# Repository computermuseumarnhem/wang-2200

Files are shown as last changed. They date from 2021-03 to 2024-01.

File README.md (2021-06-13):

# Wang 2200

I'd like to get this thing working again.

Therefore:

## Extension cards

I've created extension cards to be able to raise the the processor and interface cards out of the card cage. The boards are 8" (203.20 mm) long 
and 2.50" (63.5 mm) wide. In total three extension cards are needed for a full processor board, and two for an interface card, or the power regulator
card.

Features are:

- The card is raised outside the card cage and rotated 90 degrees (component side up). That makes it easy to probe signals with a multimeter or oscilloscope.
- A standard 2x15 0.1" header is provided that connects to all connection points on the card edge, for easy attachment of logic analyzer probes

## Power supply

The power supply consists of three parts

1. The transformer, the bulk filter capacitors, and a few resistors and diodes on the main board
2. The regulator board with the low power parts of the (linear) regulators (board L567)
3. The heat sink with the high power parts of the regulators (transistors and rectifiers)

The transformer and bulk filter capacitors are either soldered or screwed to the main board. The resistors and diodes are also soldered on the mainboard.

The regulator board is using the regular card edges (two 2 &times; 15 pads), also used on the other boards. These card edges mate with EDAC 307-030-520-201 card edge connectors.

The heat sink uses two TE Commercial MATE-N-LOK connectors, one 12 position (1-480287-0) and one 16 position (1-480438-0). The regulator board connects to the heat sink via the main board.

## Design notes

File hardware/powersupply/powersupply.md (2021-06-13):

# Powersupply

The powersupply consists of two parts:

1. The large and heavy stuff, mounted to the chassis
2. Some resistors, capacitors and diodes on the main board
3. The regulator board with the regulator electonics
4. The heat sink with the power transistors and diodes

The "Schematic Logibloc Interconnection Diagram" (D-6627-999) shows how the different parts connect together. However I don't expect the reality reflects the schematic completely.

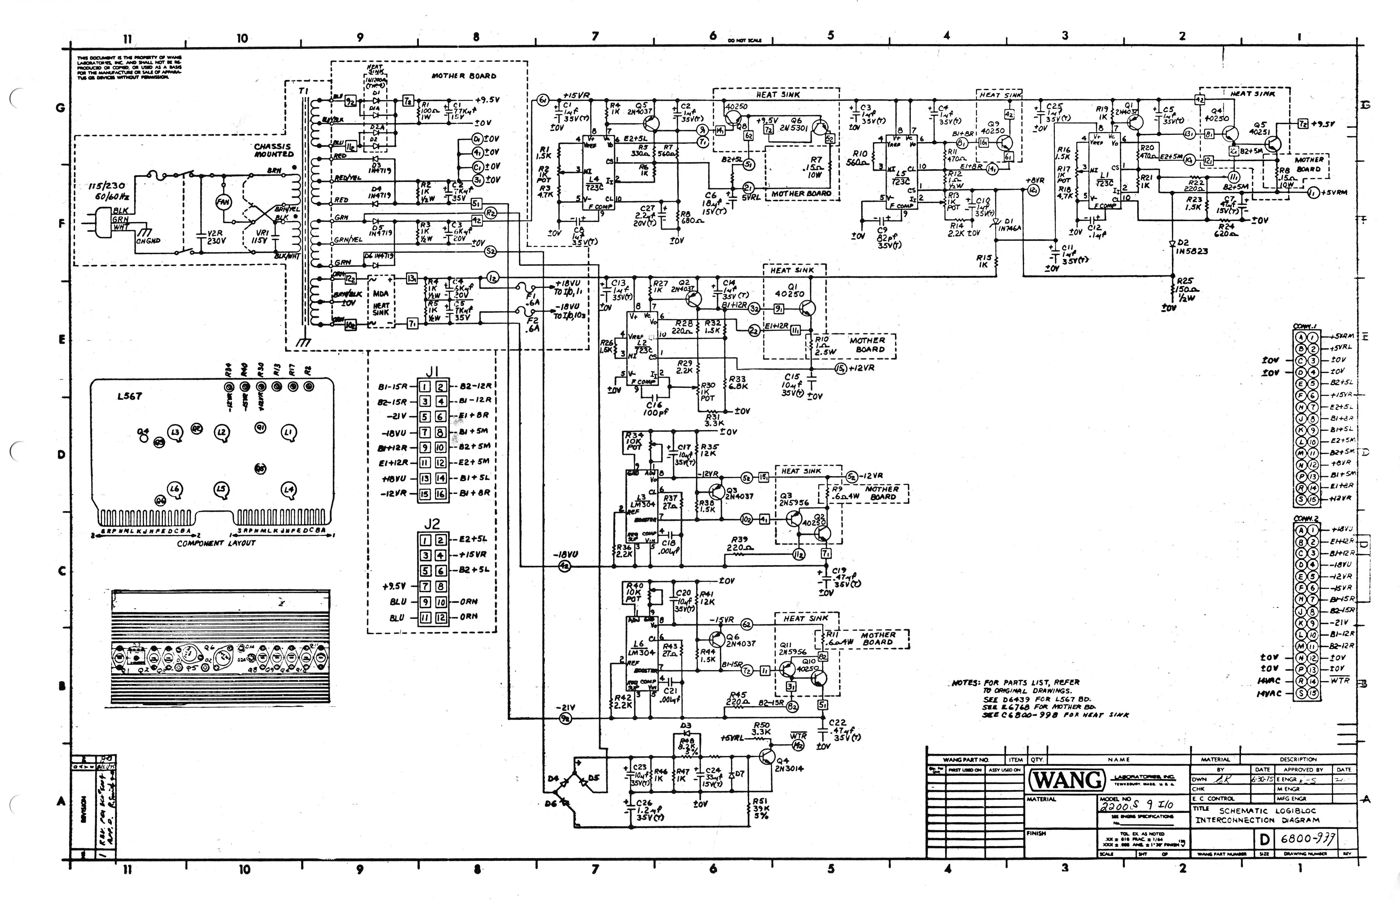
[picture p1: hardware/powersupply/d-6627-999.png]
D-6627-999


## 1. Large and heavy

The transformer is probably the largest and heaviest in the system. So this one's here. So is the cooling fan. Also the mains filter capacitors and two of the bulk filter capacitors. The last two are mounted on the chassis, and with their terminals directly screwed to the main board.

Contrary to the schematic, the mains filter capacitors are mounted to a small-ish circuit board, together with what looks like a large resistor, but could be anything (a cylinder 7.25mm diameter, 23 mm long, colour bands: silver, red, red, black, silver)

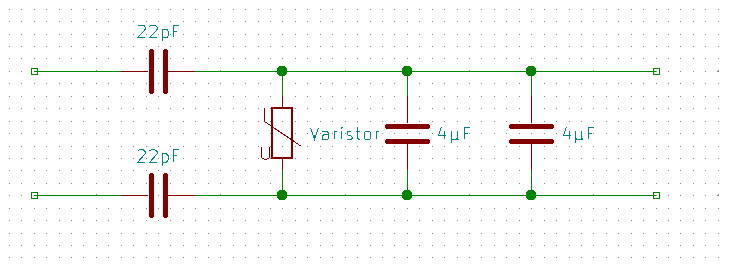
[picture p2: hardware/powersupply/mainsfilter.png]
Mains filter


## 2. Mainboard

The mainboard does al the interconnects between the chassis mounted parts, the regulator board and the heat sink (as well as the actual computer boards).

It also holds the four diodes forming the two rectifier sets for the +5V and the -15V, as well as the current sensing resistors for all power rails.

## 3. Regulator

The regulator board contains the regulators for all power rails, and the trim potentiometers to set the correct values.

## 4. Heat sink

Mounted on the heat sink, the power transistors do the grunt work for the regulators, with some space left for two rectifier diodes for the +5V and a bridge rectifier for the +12VR and -12VR

[d-6627-999]: ./d-6627-999.png "Schematic Logibloc Interconnection Diagram (D-6627-999)"
[mainsfilter]: ./mainsfilter.png "Mains filter"

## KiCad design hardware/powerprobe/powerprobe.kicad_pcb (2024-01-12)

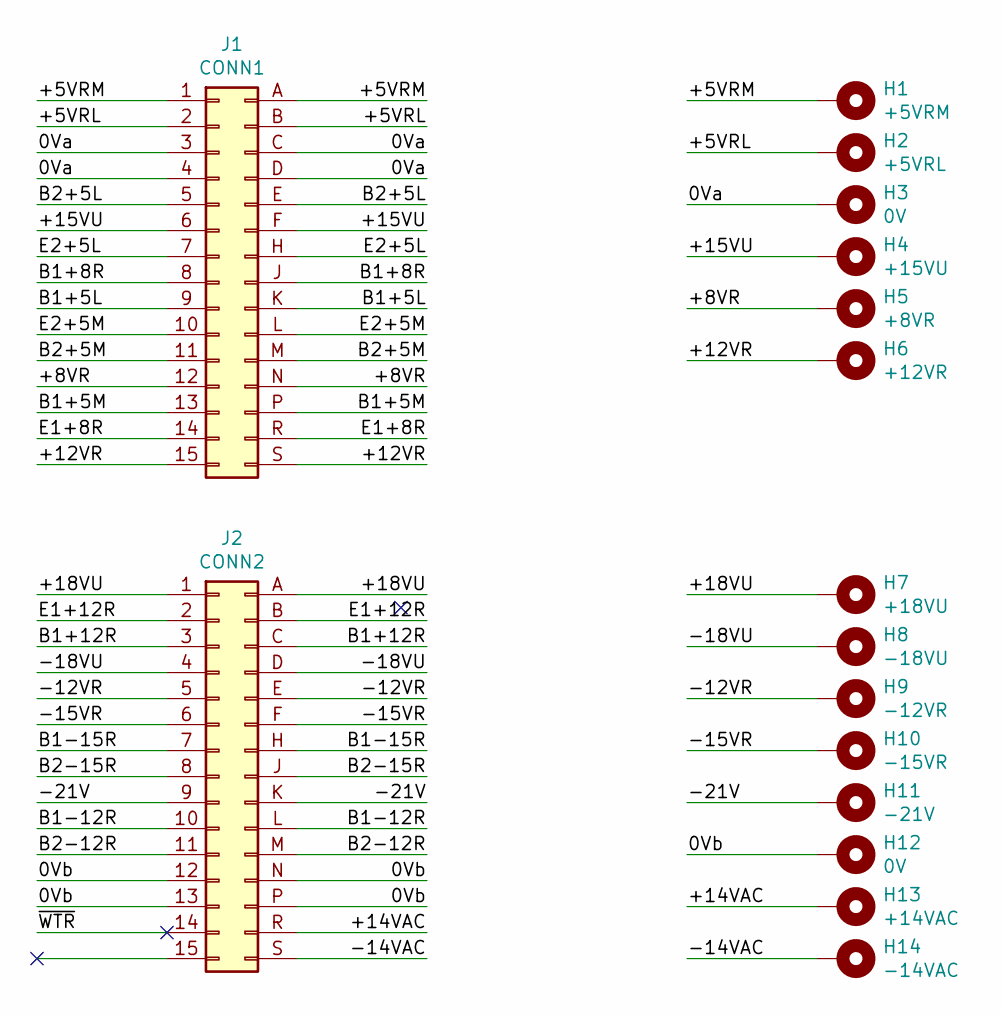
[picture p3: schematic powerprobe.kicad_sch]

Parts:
H1: +5VRM; MountingHole_4mm_Pad
H2: +5VRL; MountingHole_4mm_Pad
H3, H12: 0V; MountingHole_4mm_Pad
H4: +15VU; MountingHole_4mm_Pad
H5: +8VR; MountingHole_4mm_Pad
H6: +12VR; MountingHole_4mm_Pad
H7: +18VU; MountingHole_4mm_Pad
H8: -18VU; MountingHole_4mm_Pad
H9: -12VR; MountingHole_4mm_Pad
H10: -15VR; MountingHole_4mm_Pad
H11: -21V; MountingHole_4mm_Pad
H13: +14VAC; MountingHole_4mm_Pad
H14: -14VAC; MountingHole_4mm_Pad
J1: CONN1; PinSocket_2x15_P2.54mm_Horizontal
J2: CONN2; PinSocket_2x15_P2.54mm_Horizontal

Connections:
/0Va: H3.1, J1.3, J1.4, J1.C, J1.D
/0Vb: H12.1, J2.12, J2.13, J2.N, J2.P
/+5VRL: H2.1, J1.2, J1.B
/+5VRM: H1.1, J1.1, J1.A
/+8VR: H5.1, J1.12, J1.N
/+12VR: H6.1, J1.15, J1.S
/+14VAC: H13.1, J2.R
/+15VU: H4.1, J1.6, J1.F (G)
/+18VU: H7.1, J2.1, J2.A
/-12VR: H9.1, J2.5, J2.E
/-14VAC: H14.1, J2.S
/-15VR: H10.1, J2.6, J2.F (G)
/-18VU: H8.1, J2.4, J2.D
/-21V: H11.1, J2.9, J2.K
/B1+5L: J1.9, J1.K
/B1+5M: J1.13, J1.P
/B1+8R: J1.8, J1.J
/B1+12R: J2.3, J2.C
/B1-12R: J2.10, J2.L
/B1-15R: J2.7, J2.H
/B2+5L: J1.5, J1.E
/B2+5M: J1.11, J1.M
/B2-12R: J2.11, J2.M
/B2-15R: J2.8, J2.J
/E1+8R: J1.14, J1.R
/E1+12R: J2.2, J2.B
/E2+5L: J1.7, J1.H
/E2+5M: J1.10, J1.L

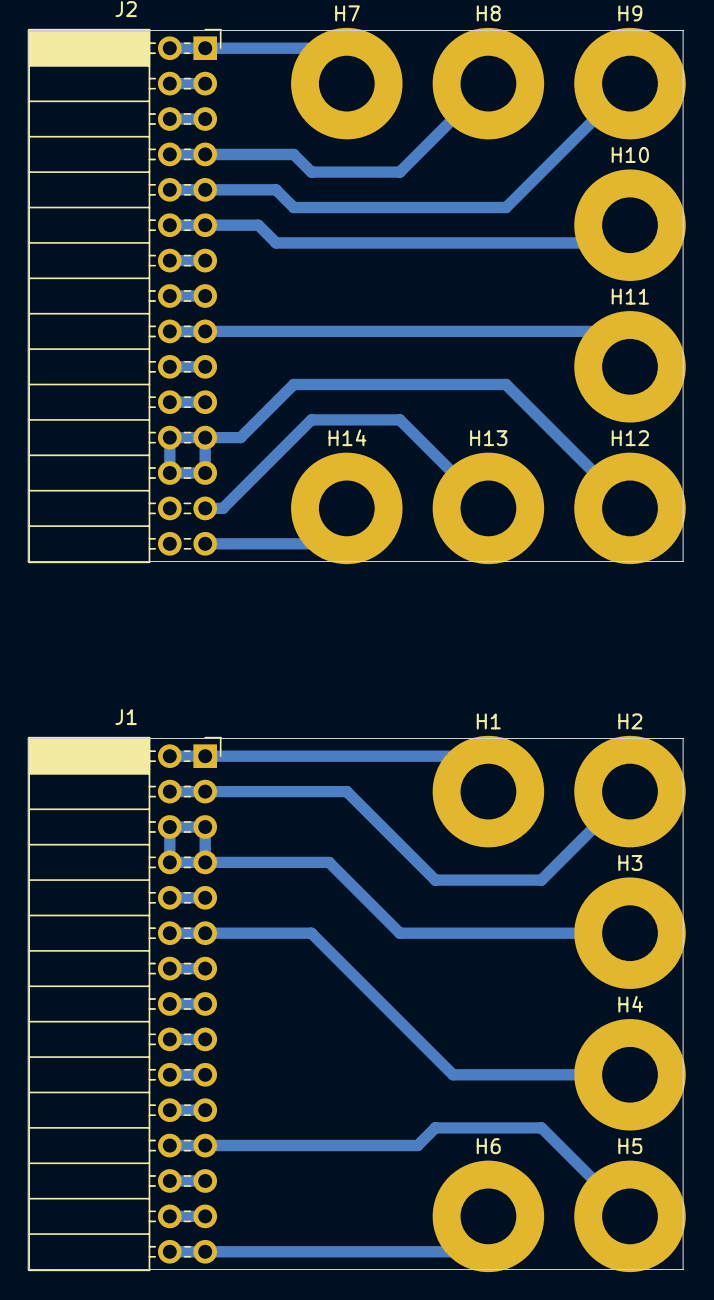
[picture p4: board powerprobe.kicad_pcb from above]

Board: 2 copper layers, 47.0 x 88.9 mm, 16 parts (0 on the bottom side), 28 nets.

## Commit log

2021-03-19 extensioncard hopefully done
    [307-030-520-201 - EDAC Card Edge Connector.step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]
2021-06-13 some power supply updates
    [L567.sch, WTR.sch]
2024-01-12 upcycled to newer version KiCad
    [extensioncard.kicad_pcb, extensioncard.kicad_sch, extensioncard.sch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]
2024-10-08 small update in schematic
    [heatsink.kicad_pcb, heatsink.kicad_sch, minus12VR.kicad_sch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]
2025-09-13 moved extensioncard away
    [307-030-520-201 - EDAC Card Edge Connector.step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]
